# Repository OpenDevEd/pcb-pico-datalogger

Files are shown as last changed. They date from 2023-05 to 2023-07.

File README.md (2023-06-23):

Pico Datalogger with Integrated Power-Management
================================================

This is a breakout supporting low-frequency data-logging with a Raspberry Pi Pico.

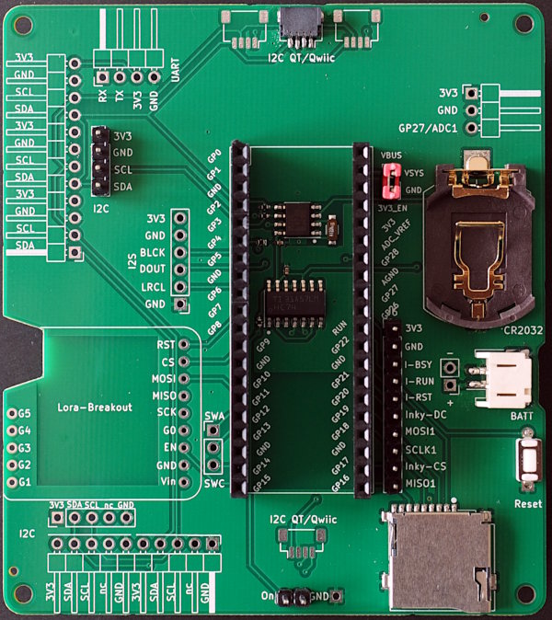
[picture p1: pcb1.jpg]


Core functions:
  * log data to a micro-sd card;
  * software-controlled power-control with very low standby current.

From a technical viewpoint the breakout allows you to
  * turn on the system using a button or
  * use a RTC-alarm to trigger wakup,
  * turn off the system using a dedicated digital-io,
  * power the system from a lipo or battery-pack,
  * keep time using a coincell backup-battery even if the board is not powered.

Hardware Components
-------------------

Time-keeping uses the PCF8523 RTC with integrated support for a backup-battery.

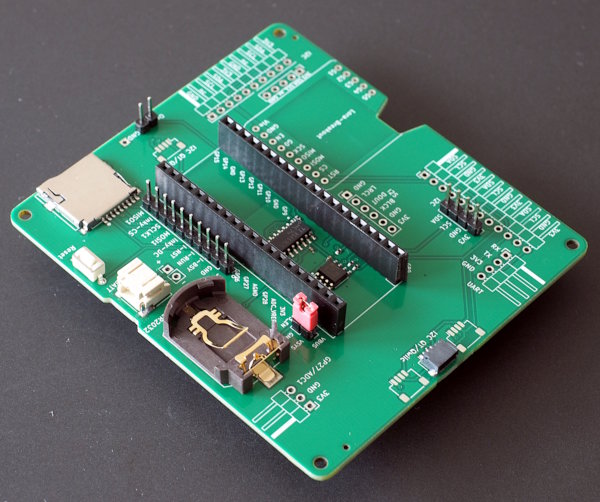
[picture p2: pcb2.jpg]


Power management uses a D-type flip-flop which drives the enable pin of the Pico.
In "reset"-state, the enable pin is pulled high and the Pico is running. The
reset is triggered either by a button, or by an RTC-alarm.

The "done"-pin of the Pico is connected to the CLK-pin of the flip-flop. A rising edge
will toggle the enable pin.

A micro-sd card reader is connected to SPI to enable logging of data.

Various additional connectors allow the user to connect sensors or displays.

Background
----------

For background on / motivation for this project, please see
<https://opendeved.net/programmes/ilce-in-tanzania/>.

Additional resources
--------------------

  * [Sensors](sensors.md)
  * [Components](components.md)
  * [Power](power.md)
  * [Hardware setup](hardware_setup.md)
  * [Pinout](pins.md)
  * Case for this PCB: https://github.com/OpenDevEd/case-for-pico-datalogger-rev1.00
  * [Software](datacollector.md)
  * [KiCAD design-files](./pico-datalogger.kicad/Readme.md)
  * [References](references.md)

License
-------

Software in `src` is licensed under the GPL3. Hardware is licensed by:

[![CC BY-SA 4.0][cc-by-sa-shield]][cc-by-sa]

This work is licensed under a
[Creative Commons Attribution-ShareAlike 4.0 International
License][cc-by-sa].

[][cc-by-sa]

[cc-by-sa]: http://creativecommons.org/licenses/by-sa/4.0/
[cc-by-sa-image]: https://licensebuttons.net/l/by-sa/4.0/88x31.png
[cc-by-sa-shield]:
https://img.shields.io/badge/License-CC%20BY--SA%204.0-lightgrey.svg

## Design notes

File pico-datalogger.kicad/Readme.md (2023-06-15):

KiCAD-Designfiles
=================

Here are the KiCAD (v6) design-files for the Datalogger-PCB.

Schematic
---------

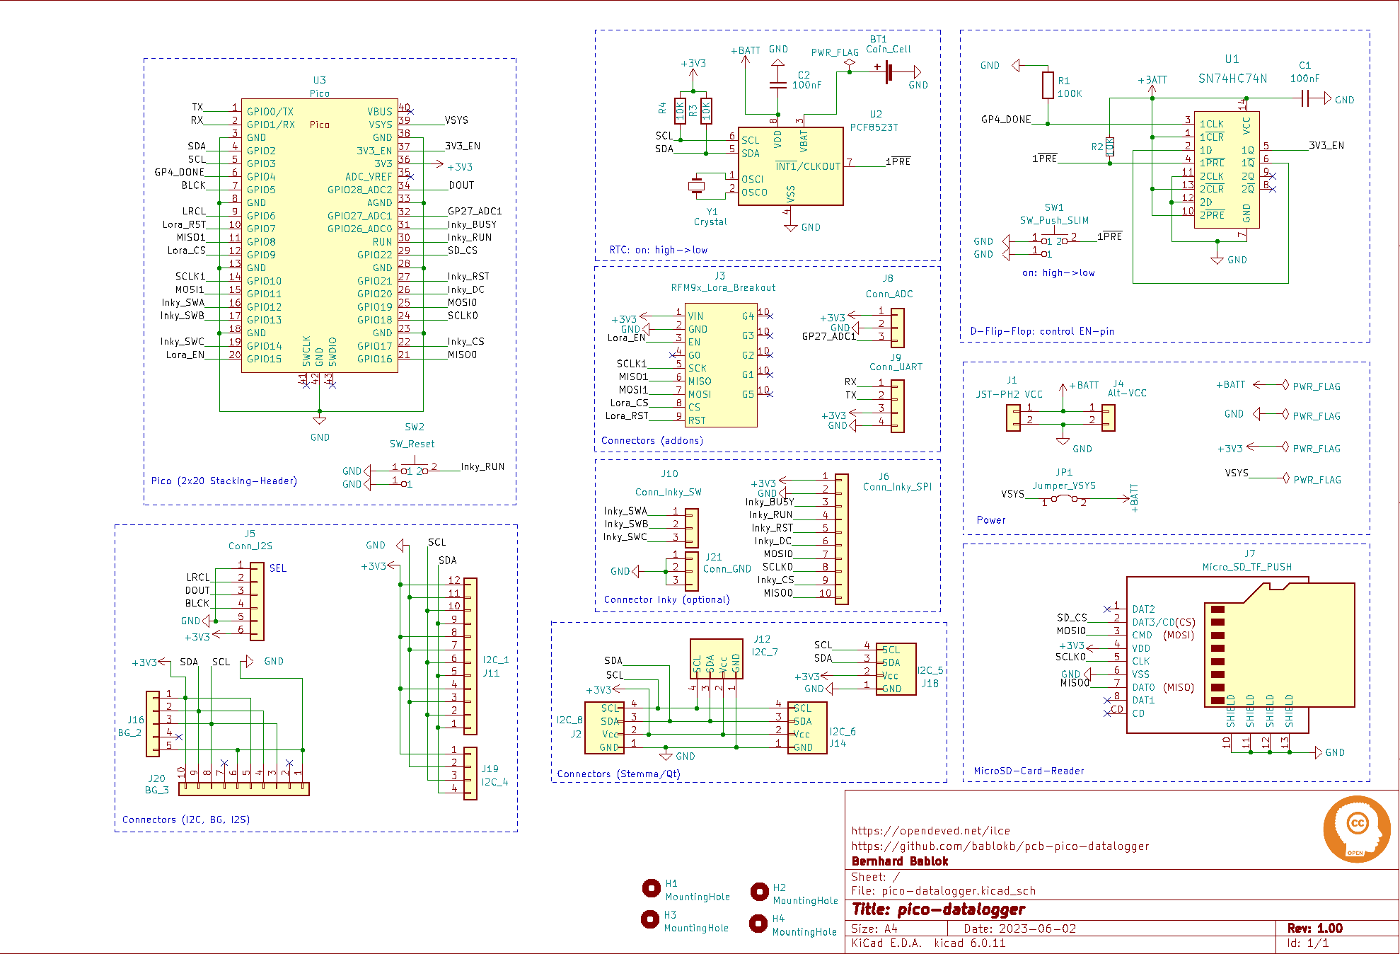
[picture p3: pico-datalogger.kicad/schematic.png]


Layout
------

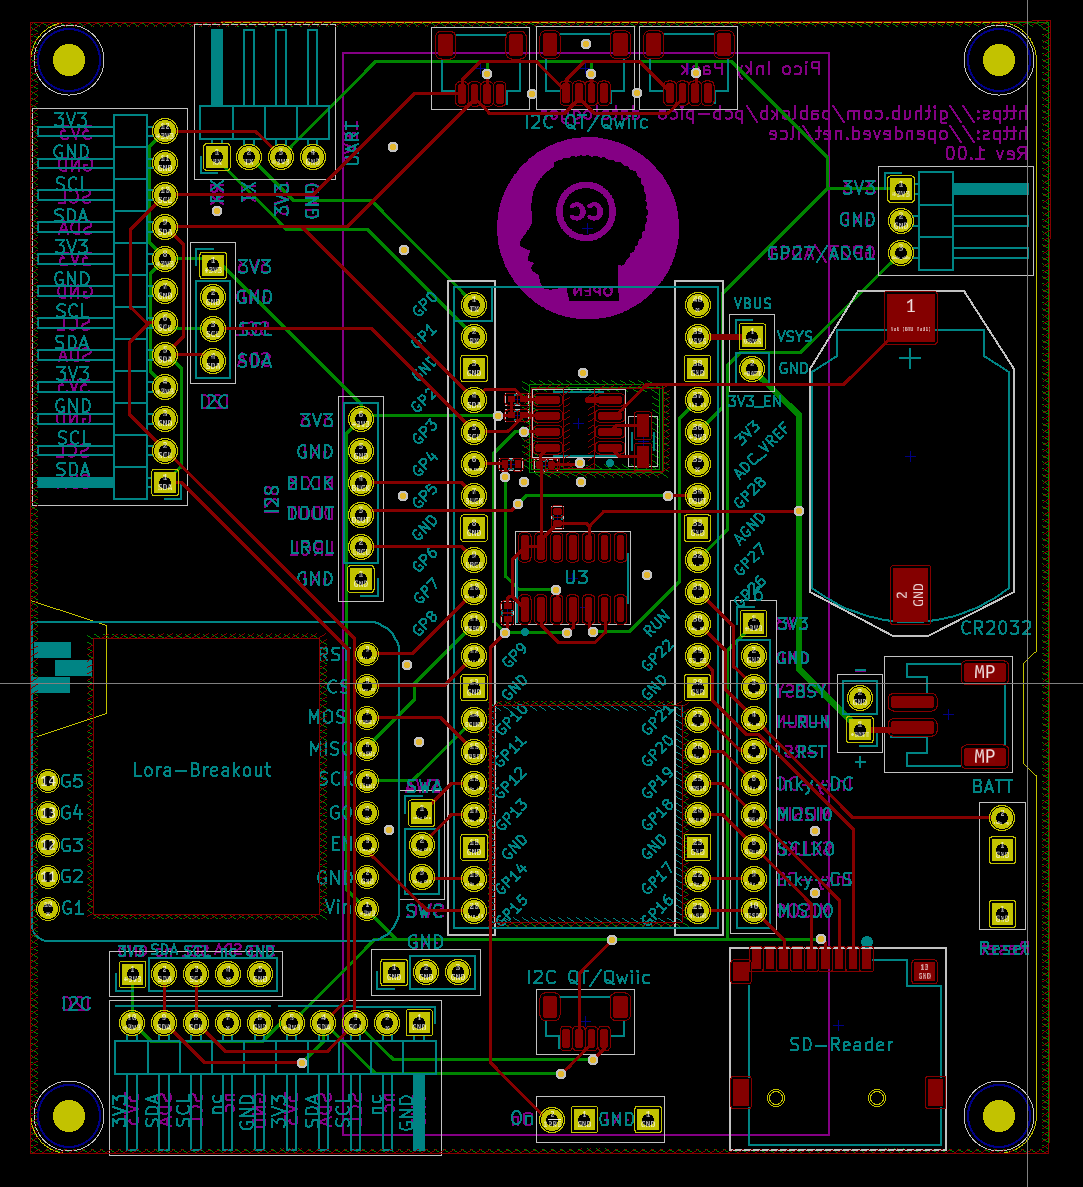
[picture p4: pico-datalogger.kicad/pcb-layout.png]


3D-Views
--------

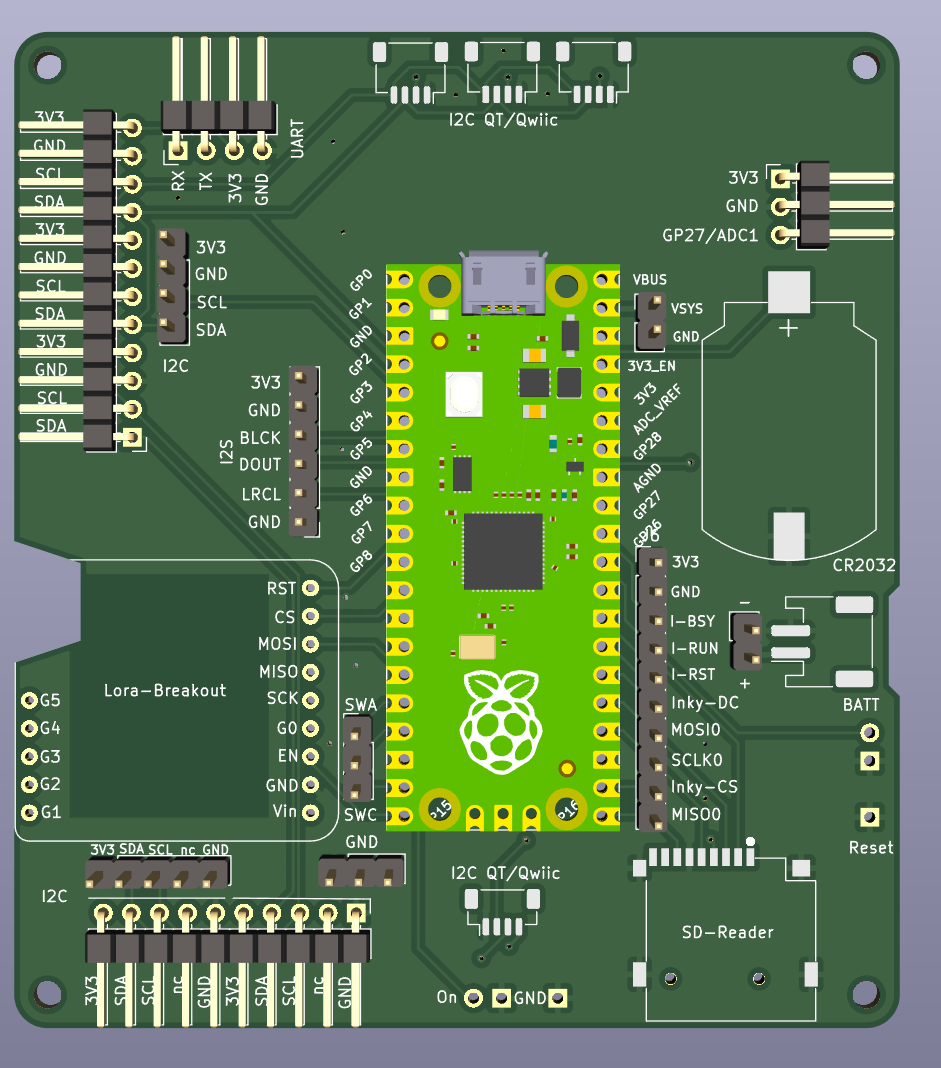
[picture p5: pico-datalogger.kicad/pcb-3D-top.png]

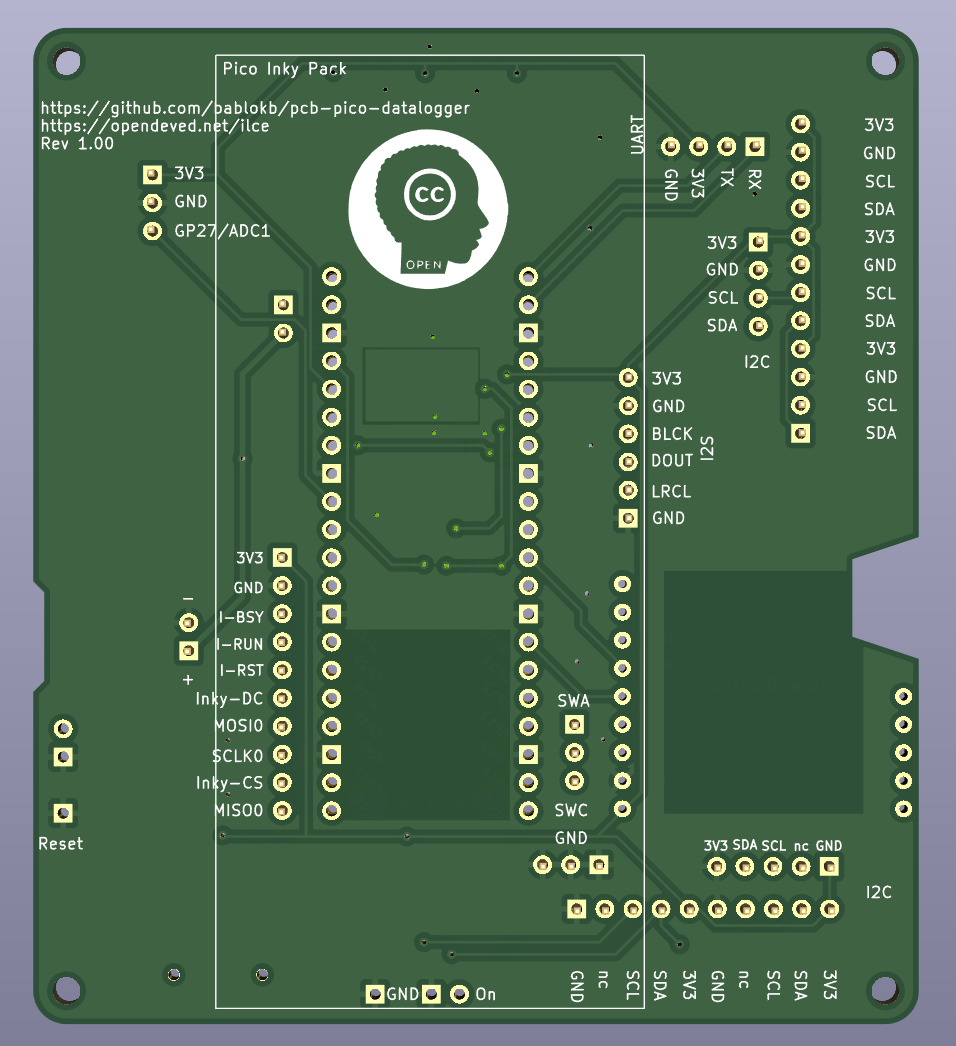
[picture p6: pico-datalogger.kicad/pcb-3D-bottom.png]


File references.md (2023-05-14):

Links
=====

This is a collection of links to products, datasheets, documentation and so on.

Datasheets for hardware used in conjunction with the board
----------------------------------------------------------

Required:
- Raspberry Pi Pico or Pico W (https://www.raspberrypi.com/products/raspberry-pi-pico/) or a pin-compatible device, such as the [Pico Lipo](https://shop.pimoroni.com/products/pimoroni-pico-lipo), is required for the operation of the board. Details on which device to chose are below.

Optional:
- Adafruit RFM96W LoRa Radio Transceiver Breakout - 433 MHz - RadioFruit:  
  <https://www.adafruit.com/product/3073>
  This is optional. It is used for offloading data from the Pico to a 'base station'. If you have public LoRa gateways where you are, you can also use one of those gateways.
  *Important:* We are selecting the 433 MHz version of this board, as this is the appropriate frequency for Tanzania. There is an 868 / 915 MHz version available https://www.adafruit.com/product/3072.
- Pico Inky Pack:  
  <https://shop.pimoroni.com/products/pico-inky-pack>
  Used to shows sensor data.
- A micro-SD card

The board is intended to be used mainly with I2C sensors. We have not finalised the selection of sensors, but are evaluating the following sensors:
- AHT20 (temperature and humidity), [Adafruit with Qw/ST](https://www.adafruit.com/product/4566), [data sheet](https://cdn-learn.adafruit.com/assets/assets/000/091/676/original/AHT20-datasheet-2020-4-16.pdf?1591047915), I2C address 0x38
- Asair AM2301B in enclosure [datasheet](https://cdn-shop.adafruit.com/product-files/5181/5181_AM2301B.pdf), I2C address 0x38
- SHT45 (temperature and humidity), https://sensirion.com/products/catalog/SHT45/
- MCP9808 (temperature), https://ww1.microchip.com/downloads/en/DeviceDoc/25095A.pdf
- BH1745 (light)
- LTR-559 (light)
- MEMS Microphone (details to follow)

Please note that many of the Adafruit versions of the above sensors are fitted with an LED. For some sensors, this can be disabled by cutting a track, but for others there is no straightforward way of diabling the LED.

Picking the right micro controller for connectivity and storage
----

How will you store data? The Pico has only provided 848 kB with MicroPython installed, much of which will be taken up by software. If you do not 'offload data' (or want your data to be storage on the device), you need more storage.
- If 'offload data' via LoRa, and do not need storage on the device, use any of the above (Pico, Pico W, Pico Lipo)
- If you do need storage on the device, you can use either:
  - Any of the above devices together with a mico-SD card, inserted into the micro-SD card slot of our device. This has the disadvantage that the micr-SD card is an extra expense. However, the advantage is that you get a large amount of storage.
  - If you measure infrequently (e.g., a few times an hour), then your storage needs may only be a few MB. If you do not want to use an SD card, and you do not need WiFi, you can use the Pico Lipo (4 MB or 16 MB).

Do you need WiFi? WiFi could be useful if you want to use the device in a setting where there is a WiFi network readily available. WiFi could also be useful for accessing the device for inspection (similarly to configuring an https://shop.pimoroni.com/products/enviro-indoor). 
- If you need WiFi (instead of LoRa or in addition to LoRa), use the Pico W.
- Otherwise use the Raspberry Pi Pico or the Pimoroni Pico Lipo.

Power
-----
The board needs to be powered with one of the following options:
- Two AA or AAA batteries
- AA or AAA rechargeables (take care to get the 'slow discharge' type)
- A LiPo battery

The RTC requires a CR2032 cell. The RTC is powered separately, so that the batteries can be changed without losing time.

Datasheets for components used on the board
-------------------------------------------

Note: some of the components can be replaced with similar components but this might
need some rework on the pcb.

- PCF8523: <https://www.nxp.com/docs/en/data-sheet/PCF8523.pdf>
- SN74HC74: <https://www.ti.com/lit/ds/symlink/sn74hc74.pdf>
- Micro-SD Card Reader/connector/socket: <https://datasheet.lcsc.com/lcsc/1912111437_SHOU-HAN-TF-PUSH_C393941.pdf>
- Oscillator: <https://datasheet.lcsc.com/lcsc/1810171817_Seiko-Epson-Q13FC1350000400_C32346.pdf>
- CR2032-Holder: <https://datasheet.lcsc.com/lcsc/2012121836_MYOUNG-BS-08-B2AA001_C964777.pdf>

Software
--------

To follow.

Background
----------
For background on / motivation for this project, please see https://opendeved.net/programmes/ilce-in-tanzania/.

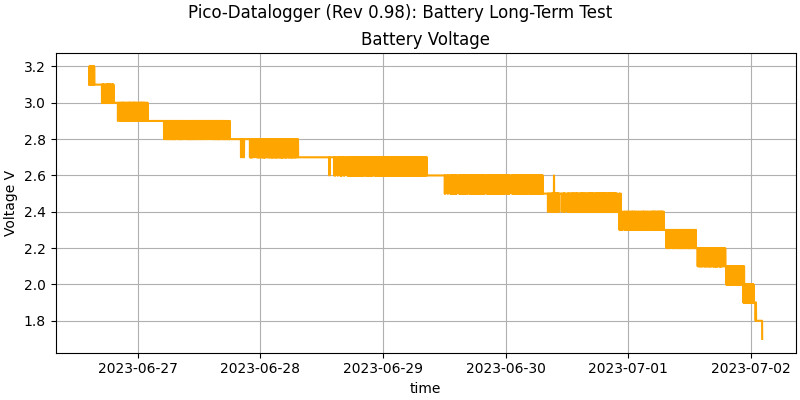
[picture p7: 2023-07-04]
battery-voltage.png

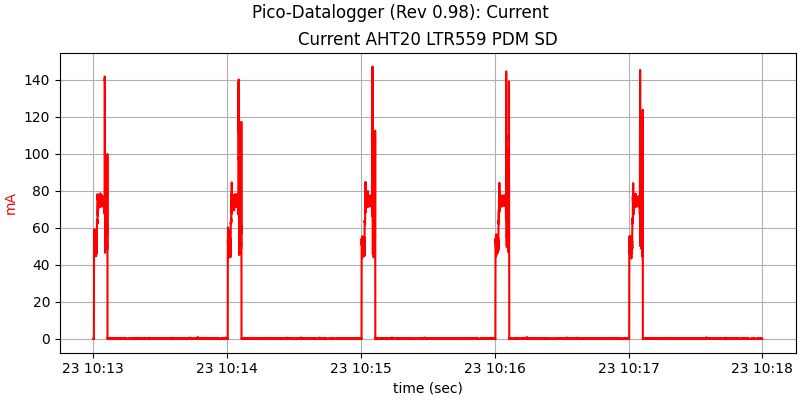
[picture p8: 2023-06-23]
current-aht20-ltr599-pdm-sd.png

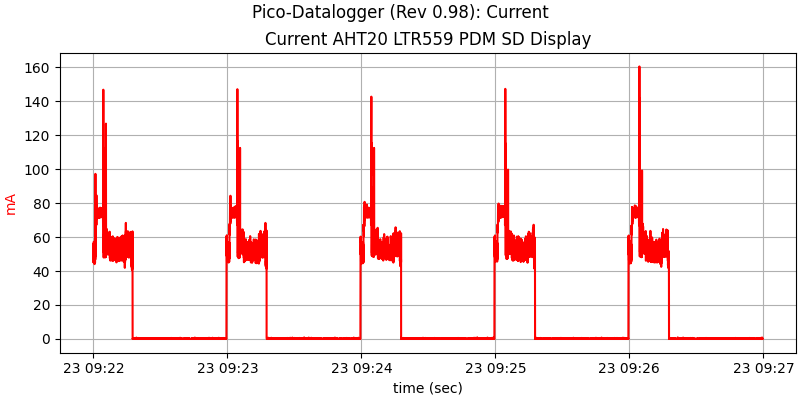
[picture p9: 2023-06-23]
current-aht20-ltr599-pdm-sd-display.png

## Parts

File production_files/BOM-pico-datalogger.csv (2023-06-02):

Comment | Designator | Footprint | LCSC
100nF | C1,C2 | C_0402_1005Metric | C1525
100K | R1 | R_0402_1005Metric | C25741
10K | R2,R3,R4 | R_0402_1005Metric | C25744
PCF8523T | U2 | SOIC-8_3.9x4.9mm_P1.27mm | C2651516
Crystal | Y1 | Crystal_SMD_3215-2Pin_3.2x1.5mm | C32346
Micro_SD_TF_PUSH | J7 | TF-Push | C393941
SN74HC74N | U1 | SOIC-14_3.9x8.7mm_P1.27mm | C6762
Coin_Cell | BT1 | CR2032_Holder | C964777

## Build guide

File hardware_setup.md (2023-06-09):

Hardware setup
--------------

To set up the board, you should:
* Connect AA batteries (or similar) via the battery port
* Add a coin cell to maintain data on the RTC (CR2032)
* Remove the jumper between the Pico and the coin cell
* Connect the Pico via USB cable to laptop

The put circuitpython on to the Raspberry Pi
* If you have a Pico, install https://circuitpython.org/board/raspberry_pi_pico/
* If you have a Pico W, install https://circuitpython.org/board/raspberry_pi_pico_w/

Them copy contents of the src folder onto the Pico.

When you're done with software installation
* Unplug the USB cable
* Replace the jumper

Note that if you want to update software in the future, remove the jumper first.

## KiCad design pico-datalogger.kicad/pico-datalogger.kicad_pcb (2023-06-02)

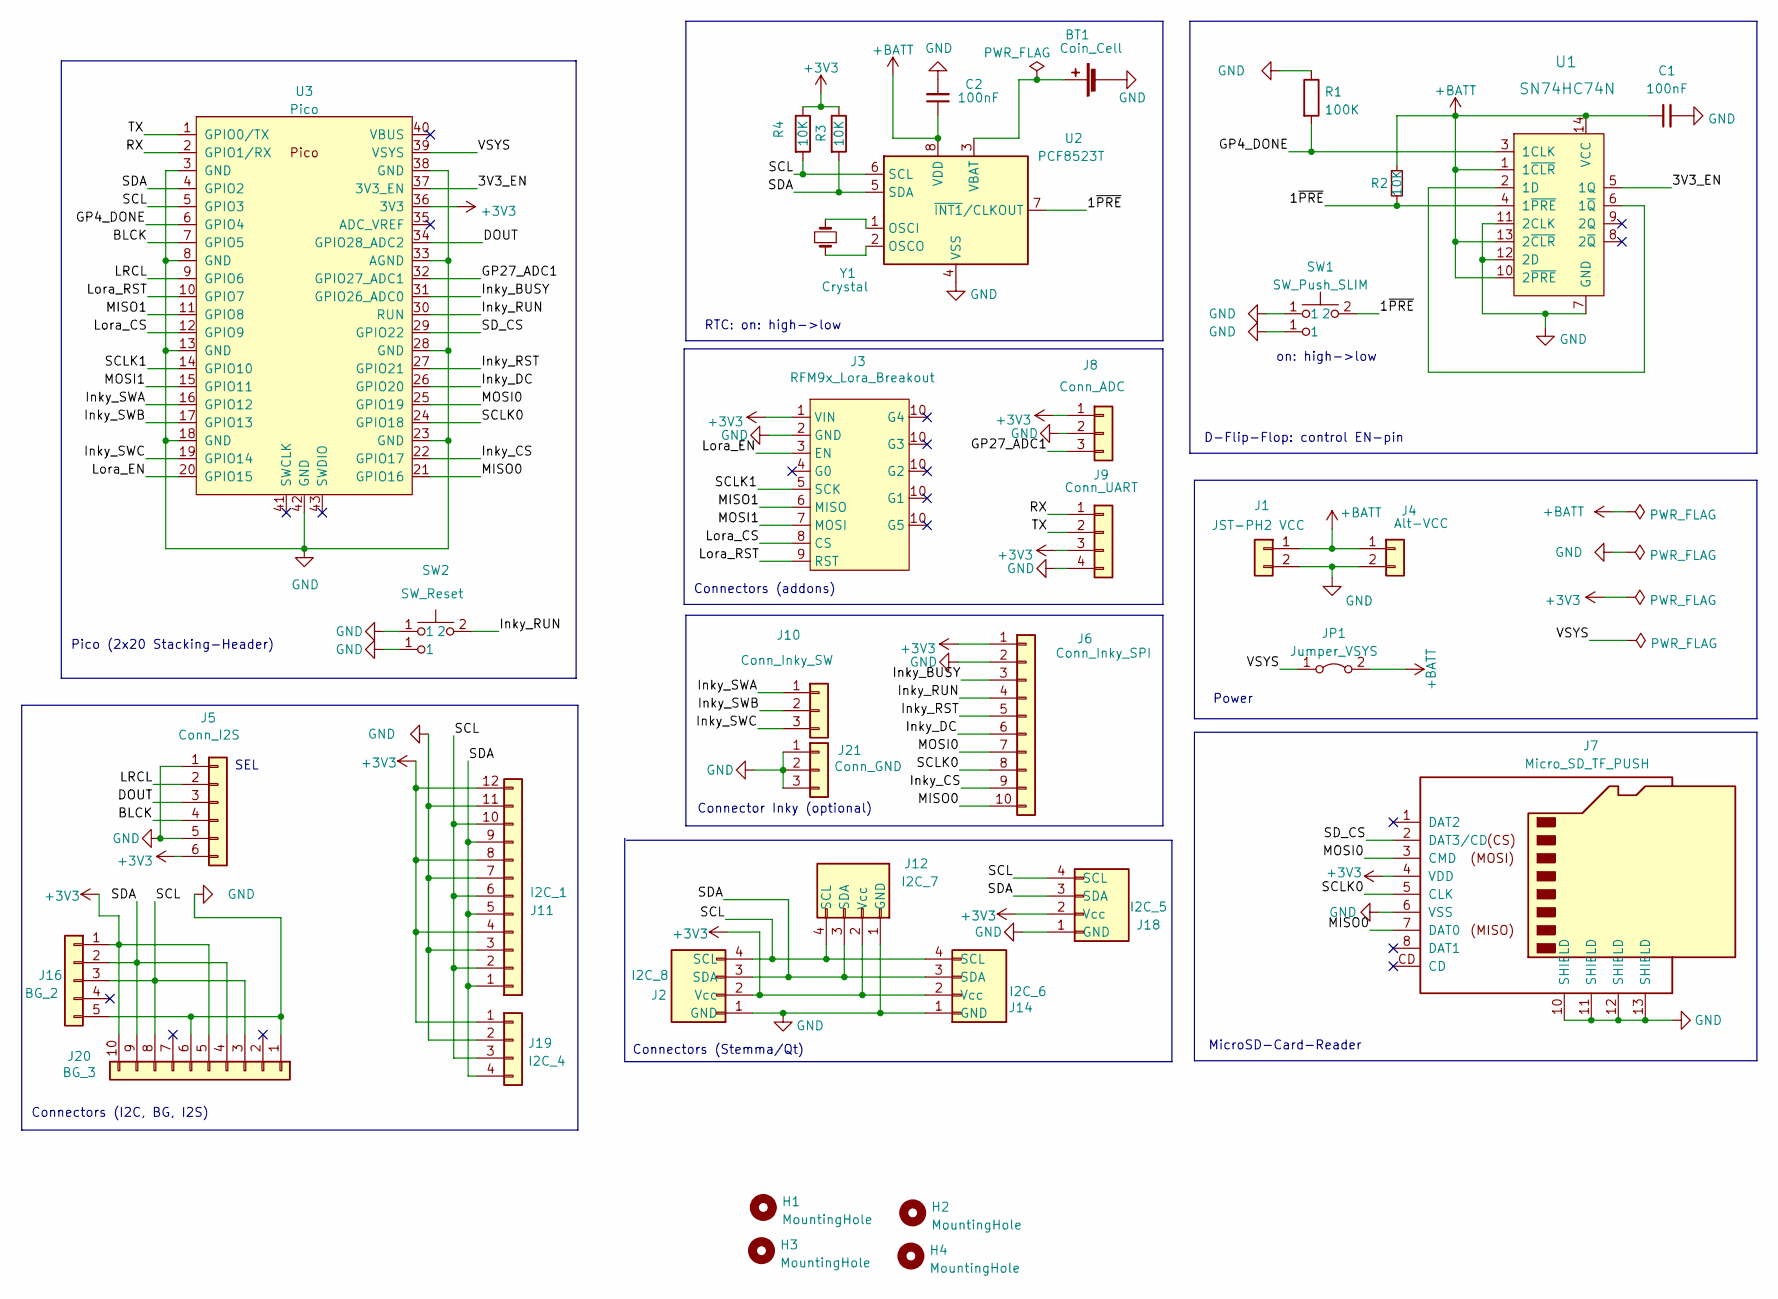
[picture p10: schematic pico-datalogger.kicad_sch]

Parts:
BT1: Coin_Cell; CR2032_Holder; LCSC C964777
C1, C2: 100nF; C_0402_1005Metric; LCSC C1525
H1, H2, H3, H4: MountingHole; MountingHole_2.5mm
J1: JST-PH2 VCC; JST_PH_S2B-PH-SM4-TB_1x02-1MP_P2.00mm_Horizontal
J2: I2C_8; JST_SH_SM04B-SRSS-TB_1x04-1MP_P1.00mm_Horizontal
J3: RFM9x_Lora_Breakout
J4: Alt-VCC; PinHeader_1x02_P2.54mm_Vertical
J5: Conn_I2S; PinHeader_1x06_P2.54mm_Vertical
J6: Conn_Inky_SPI; PinHeader_1x10_P2.54mm_Vertical
J7: Micro_SD_TF_PUSH; TF-Push; LCSC C393941
J8: Conn_ADC; PinHeader_1x03_P2.54mm_Horizontal
J9: Conn_UART; PinHeader_1x04_P2.54mm_Horizontal
J10: Conn_Inky_SW; PinHeader_1x03_P2.54mm_Vertical
J11: I2C_1; PinHeader_1x12_P2.54mm_Horizontal
J12: I2C_7; JST_SH_SM04B-SRSS-TB_1x04-1MP_P1.00mm_Horizontal
J14: I2C_6; JST_SH_SM04B-SRSS-TB_1x04-1MP_P1.00mm_Horizontal
J16: BG_2; PinHeader_1x05_P2.54mm_Vertical
J18: I2C_5; JST_SH_BM04B-SRSS-TB_1x04-1MP_P1.00mm_Vertical
J19: I2C_4; PinHeader_1x04_P2.54mm_Vertical
J20: BG_3; PinHeader_1x10_P2.54mm_Horizontal
J21: Conn_GND; PinHeader_1x03_P2.54mm_Vertical
JP1: Jumper_VSYS; PinHeader_1x02_P2.54mm_Vertical
R1: 100K; R_0402_1005Metric; LCSC C25741
R2, R3, R4: 10K; R_0402_1005Metric; LCSC C25744
SW1: SW_Push_SLIM; SW_PUSH_SLIM_1x4
SW2: SW_Reset; SW_PUSH_SLIM_1x4
U1: SN74HC74N; SOIC-14_3.9x8.7mm_P1.27mm; MPN SN74HC74N; Digi-Key_PN 296-1602-5-ND
U2: PCF8523T; SOIC-8_3.9x4.9mm_P1.27mm; LCSC C2651516
U3: Pico; RPi_Pico_TH_nodbg
Y1: Crystal; Crystal_SMD_3215-2Pin_3.2x1.5mm; LCSC C32346

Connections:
+3V3: J2.2 (Vcc), J3.1 (VIN), J5.6, J6.1, J7.4 (VDD), J8.1, J9.3, J11.4, J11.8, J11.12, J12.2 (Vcc), J14.2 (Vcc), J16.1, J18.2 (Vcc), J19.1, J20.5, J20.10, R3.1, R4.1, U3.36 (3V3)
+BATT: C1.1, C2.1, J1.1, J4.1, JP1.2 (B), R2.1, U1.1 (1~CLR), U1.10 (2~PRE), U1.13 (2~CLR), U1.14 (VCC), U2.8 (VDD)
/1~PRE: R2.2, SW1.2, U1.4 (1~PRE), U2.7 (~INT1/CLKOUT)
/3V3_EN: U1.5 (1Q), U3.37 (3V3_EN)
/BLCK: J5.4, U3.7 (GPIO5)
/DOUT: J5.3, U3.34 (GPIO28_ADC2)
/GP4_DONE: R1.2, U1.3 (1CLK), U3.6 (GPIO4)
/GP27_ADC1: J8.3, U3.32 (GPIO27_ADC1)
/Inky_BUSY: J6.3, U3.31 (GPIO26_ADC0)
/Inky_CS: J6.9, U3.22 (GPIO17)
/Inky_DC: J6.6, U3.26 (GPIO20)
/Inky_RST: J6.5, U3.27 (GPIO21)
/Inky_RUN: J6.4, SW2.2, U3.30 (RUN)
/Inky_SWA: J10.1, U3.16 (GPIO12)
/Inky_SWB: J10.2, U3.17 (GPIO13)
/Inky_SWC: J10.3, U3.19 (GPIO14)
/LRCL: J5.2, U3.9 (GPIO6)
/Lora_CS: J3.8 (CS), U3.12 (GPIO9)
/Lora_EN: J3.3 (EN), U3.20 (GPIO15)
/Lora_RST: J3.9 (RST), U3.10 (GPIO7)
/MISO0: J6.10, J7.7 (DAT0), U3.21 (GPIO16)
/MISO1: J3.6 (MISO), U3.11 (GPIO8)
/MOSI0: J6.7, J7.3 (CMD), U3.25 (GPIO19)
/MOSI1: J3.7 (MOSI), U3.15 (GPIO11)
/RX: J9.1, U3.2 (GPIO1/RX)
/SCL: J2.4 (SCL), J11.2, J11.6, J11.10, J12.4 (SCL), J14.4 (SCL), J16.3, J18.4 (SCL), J19.3, J20.3, J20.8, R4.2, U2.6 (SCL), U3.5 (GPIO3)
/SCLK0: J6.8, J7.5 (CLK), U3.24 (GPIO18)
/SCLK1: J3.5 (SCK), U3.14 (GPIO10)
/SDA: J2.3 (SDA), J11.1, J11.5, J11.9, J12.3 (SDA), J14.3 (SDA), J16.2, J18.3 (SDA), J19.4, J20.4, J20.9, R3.2, U2.5 (SDA), U3.4 (GPIO2)
/SD_CS: J7.2 (DAT3/CD), U3.29 (GPIO22)
/TX: J9.2, U3.1 (GPIO0/TX)
/VSYS: JP1.1 (A), U3.39 (VSYS)
GND: BT1.2 (-), C1.2, C2.2, J1.2, J2.1 (GND), J3.2 (GND), J4.2, J5.1, J5.5, J6.2, J7.6 (VSS), J7.10 (SHIELD), J7.11 (SHIELD), J7.12 (SHIELD), J7.13 (SHIELD), J8.2, J9.4, J11.3, J11.7, J11.11, J12.1 (GND), J14.1 (GND), J16.5, J18.1 (GND), J19.2, J20.1, J20.6, J21.1, J21.2, J21.3, R1.1, SW1.1, SW2.1, U1.7 (GND), U1.11 (2CLK), U1.12 (2D), U2.4 (VSS), U3.3 (GND), U3.8 (GND), U3.13 (GND), U3.18 (GND), U3.23 (GND), U3.28 (GND), U3.33 (AGND), U3.38 (GND), U3.42 (GND)
unnamed: BT1.1 (+), U2.3 (VBAT)
unnamed: U1.2 (1D), U1.6 (1~Q)
unnamed: U2.1 (OSCI), Y1.2
unnamed: U2.2 (OSCO), Y1.1

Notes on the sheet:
Power
Connector Inky (optional)
Pico (2x20 Stacking-Header)
Connectors (Stemma/Qt)
D-Flip-Flop: control EN-pin
SEL
RTC: on: high->low
Connectors (addons)
MicroSD-Card-Reader
Connectors (I2C, BG, I2S)
on: high->low

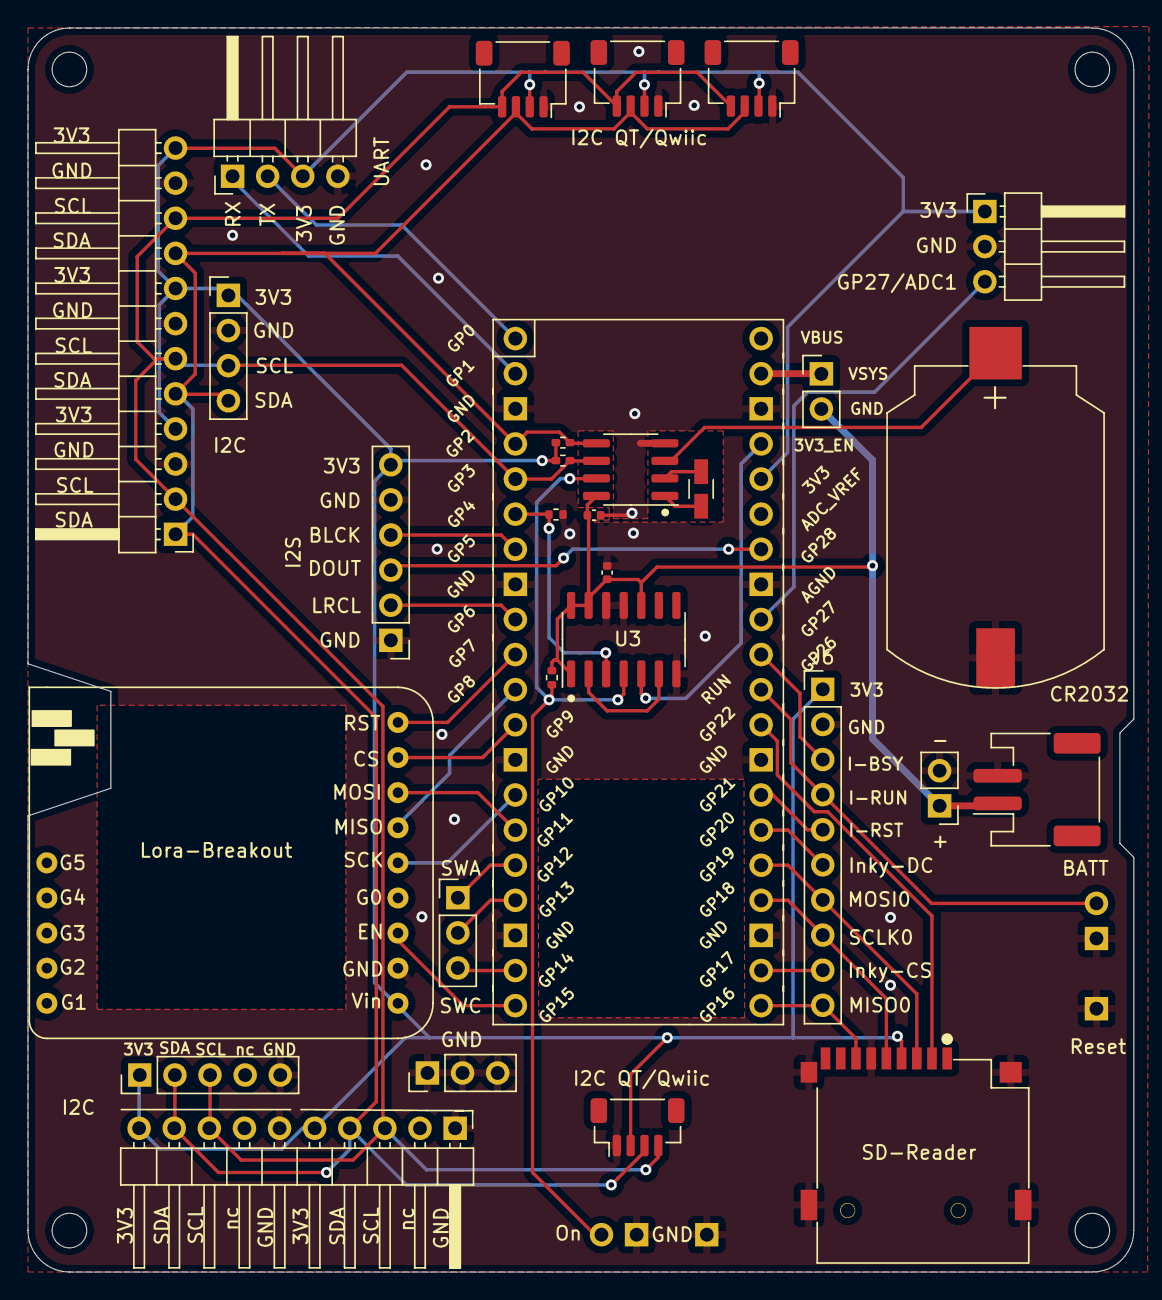
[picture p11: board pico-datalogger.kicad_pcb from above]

Board: 2 copper layers, 80.0 x 90.0 mm, 36 parts (0 on the bottom side), 37 nets.

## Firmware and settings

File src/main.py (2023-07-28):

#-----------------------------------------------------------------------------
# Basic data-collection program. This program will
#
#   - initialize hardware
#   - update RTCs (time-server->) external-RTC -> internal-RTC
#   - collect data
#   - update the display
#   - save data
#   - set next wakeup alarm
#   - turn power off
#
# Author: Bernhard Bablok
#
# Website: https://github.com/pcb-pico-datalogger
#-----------------------------------------------------------------------------

import gc
import time
import board
import alarm
import os
import builtins
import lora_range_test

from digitalio import DigitalInOut, Direction, Pull

# import for SD-card
import storage
import adafruit_sdcard
import lora

# imports for i2c and rtc
import busio
from rtc_ext.pcf8523 import ExtPCF8523 as ExtRTC

# imports for the display
import displayio
import adafruit_display_text, adafruit_display_shapes, adafruit_bitmap_font
import InkyPack

from dataviews.DisplayFactory import DisplayFactory
from dataviews.Base import Color, Justify
from dataviews.DataView  import DataView
from dataviews.DataPanel import DataPanel, PanelText


# --- early configuration of the log-destination   ---------------------------

try:
  from log_config import g_logger
except:
  from log_writer import Logger
  g_logger = Logger('console')

# --- default configuration is in config.py on the pico.
#     You can override it also with a config.py on the sd-card   -------------

class Settings:
  def import_config(self):
    """ import config-module and make variables attributes """
    import config
    for var in dir(config):
      if var[0] != '_':
        g_logger.print(f"{var}={getattr(config,var)}")
        setattr(self,var,getattr(config,var))
    config = None
    gc.collect()
g_logger.print("Starting")
g_config = Settings()
g_logger.print("importing config")
g_config.import_config()

# --- pin-constants (don't change unless you know what you are doing)   ------

PIN_DONE = board.GP4   # connect to 74HC74 CLK
PIN_SDA0  = board.GP0   # connect to sensors (alternative bus)
PIN_SCL0  = board.GP1   # connect to sensors (alternative bus)
PIN_SDA1  = board.GP2   # connect to sensors and RTC via I2C interface
PIN_SCL1  = board.GP3   # connect to sensors and RTC via I2C interface

# SD-card interface (SPI)
PIN_SD_CS   = board.GP22
PIN_SD_SCK  = board.GP18
PIN_SD_MOSI = board.GP19
PIN_SD_MISO = board.GP16

# display interface (SPI, Inky-Pack) [Shares SPI with SD card]
PIN_INKY_CS   = board.GP17
PIN_INKY_RST  = board.GP21
PIN_INKY_DC   = board.GP20
PIN_INKY_BUSY = board.GP26

# Lora interface (SPI, separate)
PIN_LORA_CS   = board.GP9
PIN_LORA_RST  = board.GP7
PIN_LORA_EN  = board.GP15
PIN_LORA_SCK  = board.GP10
PIN_LORA_MOSI = board.GP11
PIN_LORA_MISO = board.GP8
# MISO1 (LoRa)	GP8
# SCLK1 (LoRa)	GP10
# MOSI1 (LoRa)	GP11
# LoRa-RST	GP7
# LoRa-CS	GP9
# LoRa-EN	GP15

# --- main application class   -----------------------------------------------

class DataCollector():
  """ main application class """

  # --- hardware-setup   -----------------------------------------------------

  def setup(self):
    """ create hardware-objects """

    # early setup of SD-card (in case we send debug-logs to sd-card)
    if g_config.HAVE_SD:
      self._spi = busio.SPI(PIN_SD_SCK,PIN_SD_MOSI,PIN_SD_MISO)
      self.sd_cs = DigitalInOut(PIN_SD_CS)
      sdcard     = adafruit_sdcard.SDCard(self._spi,self.sd_cs)
      self.vfs   = storage.VfsFat(sdcard)
      storage.mount(self.vfs, "/sd")
      try:
        import sys
        sys.path.insert(0,"/sd")
        g_config.import_config()
        sys.path.pop(0)
      except:
        g_logger.print("no configuration found in /sd/config.py")

    # Initialse i2c bus for use by sensors and RTC
    i2c1 = busio.I2C(PIN_SCL1,PIN_SDA1)
    if g_config.HAVE_I2C0:
      i2c0 = busio.I2C(PIN_SCL0,PIN_SDA0)
    else:
      i2c0 = None

    # If our custom PCB is connected, we have an RTC. Initialise it.
    if g_config.HAVE_PCB:
      self.rtc = ExtRTC(i2c1,
        net_update=g_config.NET_UPDATE)         # this will also clear interrupts
      self.rtc.rtc_ext.high_capacitance = True  # the pcb uses a 12.5pF capacitor
      self.rtc.update()                         # (time-server->)ext-rtc->int-rtc

    self.done           = DigitalInOut(PIN_DONE)
    self.done.direction = Direction.OUTPUT
    self.done.value     = 0

    self.vbus_sense           = DigitalInOut(board.VBUS_SENSE)
    self.vbus_sense.direction = Direction.INPUT

    # display
    if g_config.HAVE_DISPLAY:

      displayio.release_displays()

      # spi - if not already created
      if not g_config.HAVE_SD:
        self._spi = busio.SPI(PIN_SD_SCK,PIN_SD_MOSI)

      if g_config.HAVE_DISPLAY == "Inky-Pack":
        self.display = DisplayFactory.inky_pack(self._spi)
      elif g_config.HAVE_DISPLAY == "Ada-2.13-Mono":
        self.display = DisplayFactory.ada_2_13_mono(
          pin_dc=PIN_INKY_DC,pin_cs=PIN_INKY_CS,
          pin_rst=PIN_INKY_RST,pin_busy=PIN_INKY_BUSY,spi=self._spi)
      elif g_config.HAVE_DISPLAY == "Display-Pack":
        self.display = DisplayFactory.display_pack(self._spi)
        self.display.auto_refresh = False
      else:
        g_logger.print(f"unsupported display: {g_config.HAVE_DISPLAY}")
        g_config.HAVE_DISPLAY = None
      self._view = None


    # just for testing
    if g_config.TEST_MODE:
      self._led            = DigitalInOut(board.LED)
      self._led.direction  = Direction.OUTPUT

    self.save_status = "__"

    #configure sensors
    self._configure_sensors(i2c0,i2c1)

  # --- configure sensors   ---------------------------------------------------

  def _configure_sensors(self,i2c0,i2c1):
    """ configure sensors """

    self._formats = []
    self.csv_header = f"#ID: {g_config.LOGGER_ID}\n#Location: {g_config.LOGGER_LOCATION}\n"
    self.csv_header += "#ts"

    self._sensors = []
    for sensor in g_config.SENSORS.split(' '):
      sensor_module = builtins.__import__(sensor,None,None,[sensor.upper()],0)
      sensor_class = getattr(sensor_module,sensor.upper())
      _sensor = sensor_class(g_config,i2c0,i2c1,None,None)
      self._sensors.append(_sensor.read)
      self._formats.extend(_sensor.formats)
      self.csv_header += f",{_sensor.headers}"

  # --- create view   ---------------------------------------------------------

  def _create_view(self):
    """ create data-view """

    # guess best dimension
    if len(self._formats) < 5:
      dim = (2,2)
    elif len(self._formats) < 7:
      dim = (3,2)
    elif len(self._formats) < 13:
      dim = (3,4)
    else:
      pass      
      # raise Exception("too many sensors")

    self._formats.extend(
      ["" for _ in range(dim[0]*dim[1] - len(self._formats))])

    border  = 1
    divider = 1
    padding = 5
    self._view = DataView(
      dim=dim,
      width=self.display.width-2*border-(dim[1]-1)*divider,
      height=int(0.6*self.display.height),
      justify=Justify.LEFT,
      fontname=f"fonts/{g_config.FONT_DISPLAY}.bdf",
      formats=self._formats,
      border=border,
      divider=divider,
      color=Color.BLACK,
      bg_color=Color.WHITE
    )

    for i in range(0,dim[0]*dim[1],2):
      self._view.justify(Justify.LEFT,index=i)
      self._view.justify(Justify.RIGHT,index=i+1)

    # create DataPanel
    title = PanelText(text=f"{g_config.LOGGER_TITLE}",
                      fontname=f"fonts/{g_config.FONT_DISPLAY}.bdf",
                      justify=Justify.CENTER)

    self._footer = PanelText(text=f"Updated: ",
                             fontname=f"fonts/{g_config.FONT_DISPLAY}.bdf",
                             justify=Justify.RIGHT)
    self._panel = DataPanel(
      width=self.display.width,
      height=self.display.height,
      view=self._view,
      title=title,
      footer=self._footer,
      border=border,
      padding=5,
      justify=Justify.CENTER,
      color=Color.BLACK,
      bg_color=Color.WHITE
    )

  # --- blink   --------------------------------------------------------------

  def blink(self, count=1, blink_time=0.25):
    for _ in range(count):
      self._led.value = 1
      time.sleep(blink_time)
      self._led.value = 0
      time.sleep(blink_time)

  # --- check for continuous-mode   ------------------------------------------

  def continuous_mode(self):
    """ returns false if on USB-power """

    return g_config.FORCE_CONT_MODE or (
            self.vbus_sense.value and not g_config.FORCE_STROBE_MODE)

  # --- collect data   -------------------------------------------------------

  def collect_data(self):
    """ collect sensor data """

    ts = time.localtime()
    ts_str = f"{ts.tm_year}-{ts.tm_mon:02d}-{ts.tm_mday:02d}T{ts.tm_hour:02d}:{ts.tm_min:02d}:{ts.tm_sec:02d}"
    self.data = {
      "ts":   ts_str
      }
    self.record = ts_str

    self.values = []
    for read_sensor in self._sensors:
      rec = read_sensor(self.data,self.values)
      self.record += f",{rec}"

  # --- check if file already exists   --------------------------------------

  def file_exists(self, filename):
    """ check if file exists """
    try:
      status = os.stat(filename)
      return True
    except OSError:
      return False

  # --- save data   ----------------------------------------------------------

  def save_data(self):
    """ save data """

    if g_config.SHOW_UNITS:
      self.pretty_print()
    else:
      g_logger.print(self.record)

    if g_config.HAVE_SD:
      ymd = self.data["ts"].split("T")[0]
      y,m,d = ymd.split("-")
      outfile = g_config.CSV_FILENAME.format(
        ID=g_config.LOGGER_ID,
        YMD=ymd,Y=y,M=m,D=d)
      new_csv = not self.file_exists(outfile)
      self.save_status = ":("
      with open(outfile, "a") as f:
        if new_csv:
          f.write(f"{self.csv_header}\n")
        f.write(f"{self.record}\n")
        self.save_status = "SD"

  # --- pretty-print data to console   ---------------------------------------

  def pretty_print(self):
    """ pretty-print data to console """

    columns = self.csv_header.split('#')[-1].split(',')
    merged = zip(columns,self.record.split(','))
    for label,value in merged:
      space = '\t\t' if len(label) < 9 else '\t'
      g_logger.print(f"{label}:{space}{value}")
    
  # --- send data   ----------------------------------------------------------

  def send_data(self):
    """ send data using LORA """
    #configure LoRa
    g_logger.print(f"Checking lora")
    if (g_config.HAVE_LORA):
      g_logger.print(f"we have lora")
      self._spi1 = busio.SPI(PIN_LORA_SCK,PIN_LORA_MOSI,PIN_LORA_MISO)
      CS = DigitalInOut(PIN_LORA_CS)
      RESET = DigitalInOut(PIN_LORA_RST)
      ENABLE = DigitalInOut(PIN_LORA_EN)
      ENABLE.direction  = Direction.OUTPUT
      self.lora = lora.LORA(433.0, self._spi1, CS, RESET, ENABLE)
      # payload = self.csv_header + "\n" + self.record
      payload = self.record
      self.lora.transmit(payload)
      time.sleep(g_config.LORA_WAIT_AFTER_SEND)
      app.blink(10,0.1)
    else:
      g_logger.print(f"No lora")



  # --- update display   -----------------------------------------------------

  def update_display(self):
    """ update display """

    gc.collect()
    if not self._view:
      self._create_view()

    # fill in unused cells
    self.values.extend([None for _ in range(len(self._formats)-len(self.values))])

    self._view.set_values(self.values)
    dt, ts = self.data['ts'].split("T")
    self._footer.text = f"at {dt} {ts} {self.save_status}"
    self.display.root_group = self._panel
    self.display.refresh()
    g_logger.print("finished refreshing display")

    if not self.continuous_mode():
      time.sleep(3)              # refresh returns before it is finished

  # --- set next wakeup   ----------------------------------------------------

  def configure_wakeup(self):
    """ configure rtc for next wakeup """
    if g_config.HAVE_PCB:
      if hasattr(g_config,"TIME_TABLE"):
        self.rtc.set_alarm(self.rtc.get_table_alarm(g_config.TIME_TABLE))
      else:
        self.rtc.set_alarm(self.rtc.get_alarm_time(m=g_config.OFF_MINUTES))

  # --- shutdown   -----------------------------------------------------------

  def shutdown(self):
    """ tell the power-controller to cut power """

    self.done.value = 1
    time.sleep(0.2)
    self.done.value = 0
    time.sleep(2)

  # --- cleanup   -----------------------------------------------------------

  def cleanup(self):
    """ cleanup ressources """

    self._spi.deinit()

# --- main program   ---------------------------------------------------------

g_logger.print("main program start")
if g_config.TEST_MODE:
  time.sleep(5)                        # give console some time to initialize
g_logger.print("setup of hardware")

if g_config.LORA_RANGE_TEST:
  lora_range_test.lora_range_test(PIN_LORA_CS,PIN_LORA_RST,PIN_LORA_EN,PIN_LORA_SCK,PIN_LORA_MOSI,PIN_LORA_MISO)
else:
  app = DataCollector()
  app.setup()
  while True:
    if g_config.TEST_MODE:
      app.blink(count=g_config.BLINK_START, blink_time=g_config.BLINK_TIME_START)

    app.collect_data()
    try:
      app.save_data()
    except:
      g_logger.print("exception during save_data()")
      app.cleanup()
      raise
      
    if g_config.TEST_MODE:
      app.blink(count=g_config.BLINK_END, blink_time=g_config.BLINK_TIME_END)

    if g_config.HAVE_DISPLAY:
      try:
        app.update_display()
      except:
        g_logger.print("exception during update_display()")
        app.cleanup()
        raise

    if g_config.HAVE_LORA:
      app.send_data()

    # check if running on USB and sleep instead of shutdown
    if app.continuous_mode():
      g_logger.print(f"continuous mode: next measurement in {g_config.CONT_INT} seconds")
      time.sleep(g_config.CONT_INT)
    else:
      break

  app.configure_wakeup()
  app.shutdown()

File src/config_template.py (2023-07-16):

#-----------------------------------------------------------------------------
# Configuration constants for main.py.
#
# !!! This file is not maintained within Github !!!
#
# Author: Bernhard Bablok
#
# Website: https://github.com/pcb-pico-datalogger
#-----------------------------------------------------------------------------

TEST_MODE   = True        # set to FALSE for a production setup
BLINK_TIME_START  = 0.5   # blink time of LED before start of data-collection
BLINK_TIME_END  = 0.25    # blink time of LED  after finish of data-collection
BLINK_START = 3           # blink n times before start of data-collection
BLINK_END   = 5           # blink n times after finish of data-collection

NET_UPDATE  = True        # update RTC from time-server if time is invalid

OFF_MINUTES = 1           # turn off for x minutes

# time table: one entry per day (starting with Monday)
#             ((h_start,h_end,h_inc),(m_start,m_end,m_inc))
# The example has Mo-Fr from 07:00-17:45 every 15 minutes
#TIME_TABLE = [
#  ((7,18,1),(0,59,15)),
#  ((7,18,1),(0,59,15)),
#  ((7,18,1),(0,59,15)),
#  ((7,18,1),(0,59,15)),
#  ((7,18,1),(0,59,15)),
#  (None,None),
#  (None,None)
#  ]

FORCE_CONT_MODE       = False      # Use continuous mode (with CONT_INT) even when on battery
FORCE_STROBE_MODE     = False      # Use strobe mode (with OFF_MINUTES) even when on power
CONT_INT              = 60         #  interval in continuous mode (in seconds)

# hardware setup
HAVE_I2C0    = False               # also use second I2C-bus
HAVE_PCB     = True                # The Pico is running on the pcb described here: https://github.com/pcb-pico-datalogger
HAVE_SD      = False               # The PCB has an sd card inserted (or an sd card is connected otherwise)
CSV_FILENAME = "/sd/log_{ID}_{YMD}.csv"
HAVE_DISPLAY = 'Inky-Pack'         # 'Inky-Pack', 'Display-Pack' or None

# Lora
HAVE_LORA    = False                # Adafruit RFM96W LoRa Radio Transceiver Breakout is avaialble
NODE_ADDRESS = 1                   # Node address
BASE_STATION_ADDRESS = 100         # Base statio=n address
LORA_RANGE_TEST = False            # If this is true, the logger does not undertake the usual functions, but just runs the range test.
LORA_ENABLE_TIME = 0               # wait time between switching on module and lora device registration
LORA_WAIT_AFTER_SEND = 0           # wait time after sending

# hardware configuration settings for sensors
SENSORS = "id battery"             # list of sensors. Each needs a <sensor>.py file

SHOW_UNITS = False # Show units in the csv output

# Logger identification constants
LOGGER_NAME  = 'Darasa Kamili'  # Perfect Classroom
LOGGER_ID    = '000'            # Change this to your logger id
# Or, if you have Lora, you can reuse the NODE_ADDRESS:
# LOGGER_ID    = '00' + str(NODE_ADDRESS)            # Change this to your logger id
LOGGER_LOCATION = '6G5X46G4+XQ' # Plus Code for Dar airport
LOGGER_TITLE = LOGGER_NAME + " " + LOGGER_LOCATION

# font for the display
FONT_DISPLAY     = 'DejaVuSansMono-Bold-18-subset'

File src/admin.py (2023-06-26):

#-----------------------------------------------------------------------------
# Start admin-mode.
#
# Author: Bernhard Bablok
#
# Website: https://github.com/pcb-pico-datalogger
#-----------------------------------------------------------------------------

import time

while True:
  print("idle in admin-mode")
  time.sleep(3)

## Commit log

2023-05-12 intial commit
    [pico-datalogger.kicad_pcb, pico-datalogger.kicad_sch]
2023-05-12 added battery and connectors
    [pico-datalogger.kicad_sch]
2023-05-12 Rev. 0.8: components with footprints
    [pico-datalogger.kicad_sch]
2023-05-12 Rev. 0.9: initial routing
    [pico-datalogger.kicad_pcb, pico-datalogger.kicad_sch]
2023-05-13 add GP0/GP1 (UART) and GP27 (ADC) to reserved pins
2023-05-13 Rev. 0.95: review for production
    [pico-datalogger.kicad_pcb, pico-datalogger.kicad_sch]
2023-05-13 Update links.md
    Added sensor data
2023-05-14 Rev 0.96: added reset-button
    [pico-datalogger.kicad_pcb, pico-datalogger.kicad_sch]
2023-05-16 fix: added 3V3 and GND for InkyPack-connector
    [pico-datalogger.kicad_pcb, pico-datalogger.kicad_sch]
2023-05-16 added I2C/BG connectors
    [pico-datalogger.kicad_pcb, pico-datalogger.kicad_sch]
2023-05-19 Rev 0.98: ready for production
    [BOM-pico-datalogger.csv, pico-datalogger.kicad_pcb, pico-datalogger.kicad_sch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]
2023-05-27 Update README.md
    Added link to case
2023-06-02 added LCSC-number to PCF8523T
    [BOM-pico-datalogger.csv]
2023-06-02 Rev 1.00: fix Stemma/Qt connectors
    [BOM-pico-datalogger.csv, pico-datalogger.kicad_pcb, pico-datalogger.kicad_sch]
2023-06-09 fixes and new features (e.g. cont-mode)
    [main.py]
2023-06-09 save_data(): print data also if we don't have a SD
2023-06-09 added images of pcb
2023-06-09 Update README.md - updated url to case
2023-06-11 Update main.py with various switches
    Added switches (most of which not implemented)
    Changed SI for Lux to lx.
2023-06-14 Manually fixing the merge - code now has PDM and latest changes from fork
    [main.py]
2023-06-15 renamed layout.png -> schematic.png
2023-06-15 moved KiCAD-related images into subdir
2023-06-15 added document linking to schematic, layout and 3D-views
2023-06-15 fixed link to Readme in KiCAD directory
2023-06-15 fixed link to Readme in KiCAD directory (again)
2023-06-15 fixed link to Readme in KiCAD directory (3rd try)
2023-06-16 switched to DejaVuSans-16
2023-06-17 Update main.py
    Added save_status to indicate issues with saving on display.
    [main.py]
2023-06-17 Update main.py
    Added csv file header writing if file doesn't exist.
    [main.py]
2023-06-18 minor fixes in csv-header
    [main.py]
2023-06-18 raise exception of sensor-count is too high
    [main.py]
2023-06-19 pretty print values on console
2023-06-19 save_data(): fix check for csv-file
    [main.py]
2023-06-21 remove sensor-specific code
2023-06-22 dynamically configure sensors
2023-06-22 pretty_print(): minor layout fix
    [main.py]
2023-06-22 refactored sensor-code
2023-06-23 renamed components.md -> sensors.md
2023-06-23 cleanup: removed power/components sections
2023-06-23 content moved from sensors.md
2023-06-23 document power-measurements
2023-06-23 updated links, including power
2023-06-23 added info about I2C0
2023-06-23 replace i2c with i2c1
    [main.py]
2023-06-23 added support for I2C0
2023-06-24 fixed power-calculation
2023-06-25 Update power.md - added spaces around * to avoid markdown
2023-06-25 Update bh1750.py
    This shoudl be i2c0, right?
2023-06-26 fixed i2c-bus for i2c0
    [ens160.py, ltr559.py]
2023-06-28 log detection of sensor
2023-06-29 write detected sensors into log
2023-07-04 fixed description of sample table
    [config_template.py]
